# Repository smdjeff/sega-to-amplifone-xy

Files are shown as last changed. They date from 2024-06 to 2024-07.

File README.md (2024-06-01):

# sega-to-amplifone-vector
Sega G80 vector to Atari Amplifone adapter

* Converts Sega's vector outputs to Atari Amplifone levels and provides buffering.
* Input supply is +5V.
* The board makes +/-12v +/-9v and +0.5v on board.
* High quality TLE2082CP can be used to double bandwidth and slew vs older TL082 op-amps.
* Doubles voltage for X & Y to reduce stress on Sega XY game board amplifiers 
* Corrects black level and scale for RGB color signals
* Simulated Sega G08 vector impedance for Sega XY board

| | Sega  | Atari |
| --- | ----- | ----- |
| X | +/-4v | +/-8v |
| Y | +/-3v | +/-6v |
| R | 0-4v  | 1.0-3.5v |
| G | 0-4v  | 1.0-3.5v |
| B | 0-4v  | 1.0-3.5v |

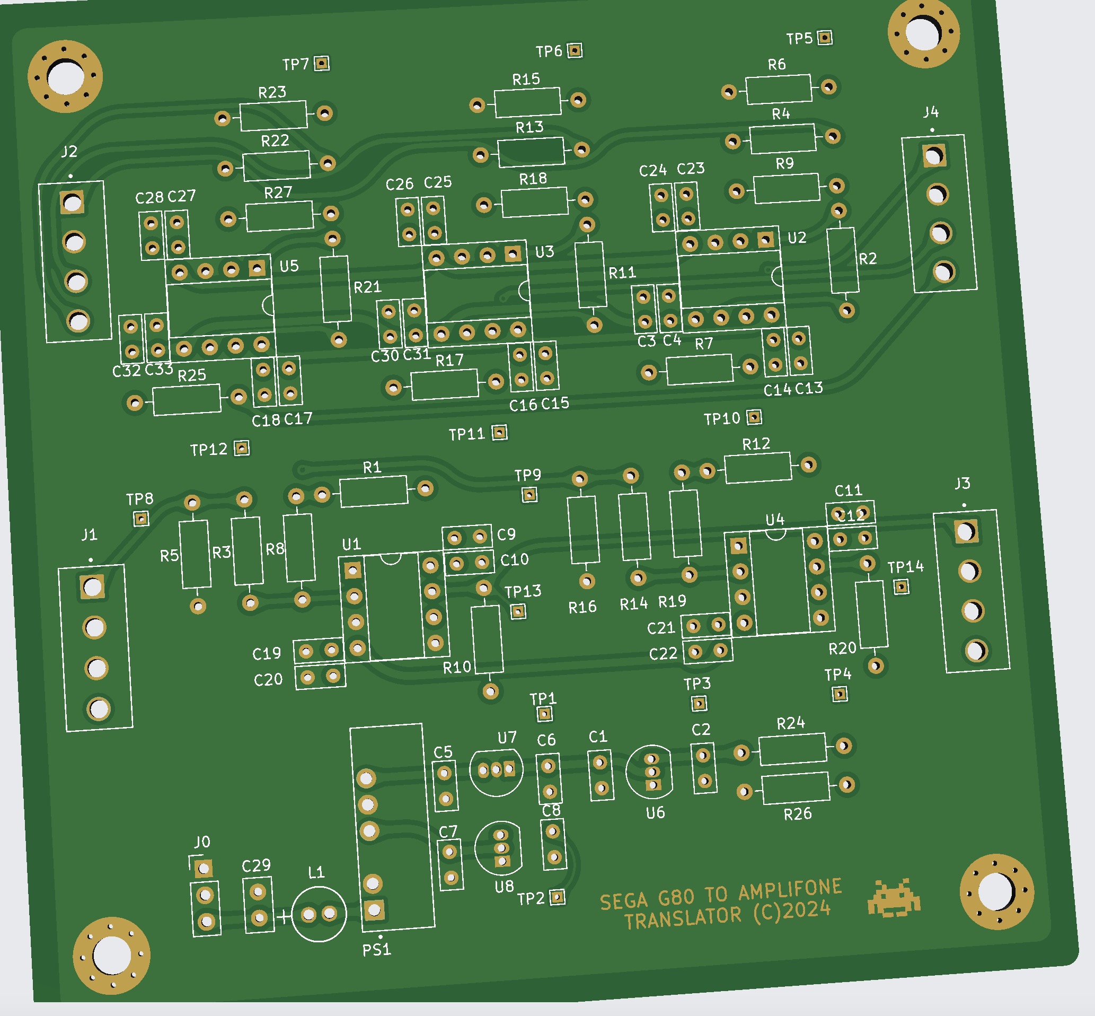
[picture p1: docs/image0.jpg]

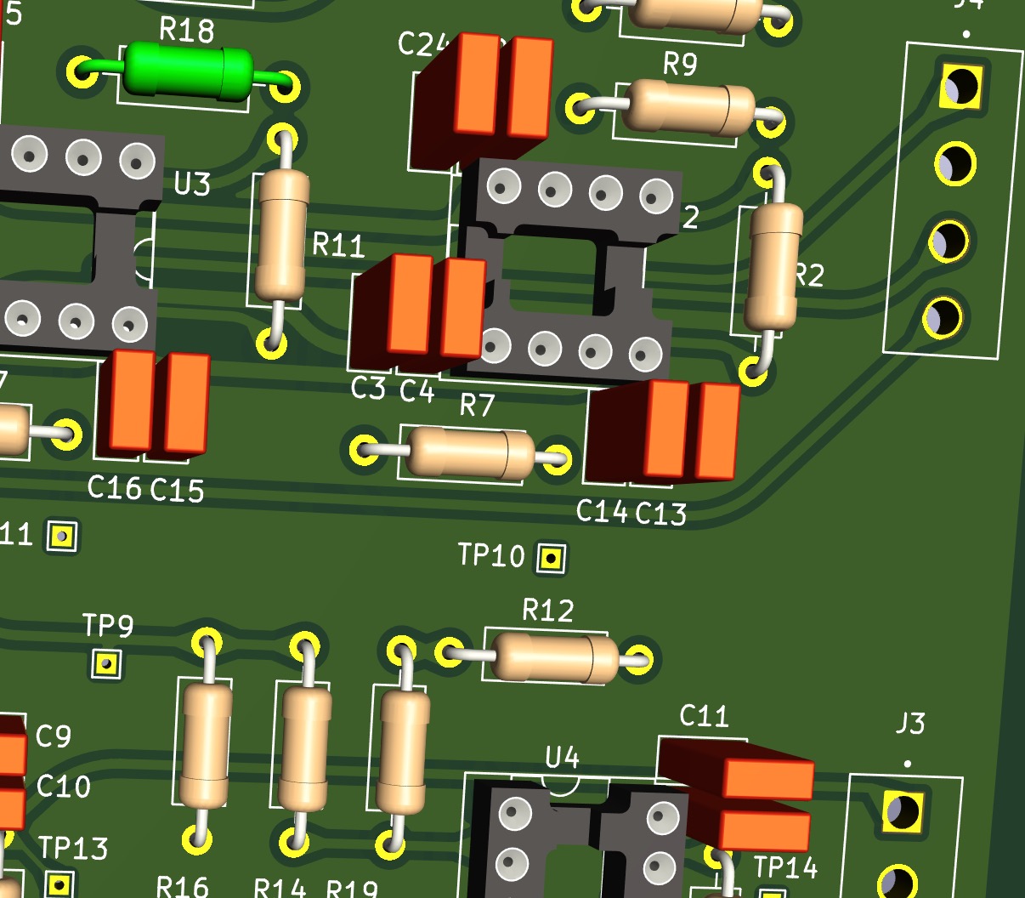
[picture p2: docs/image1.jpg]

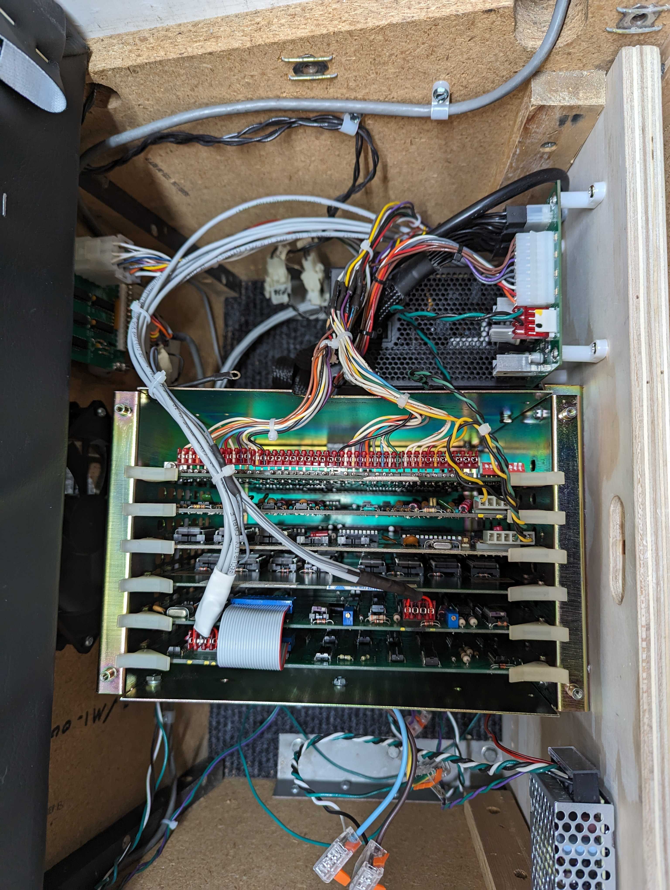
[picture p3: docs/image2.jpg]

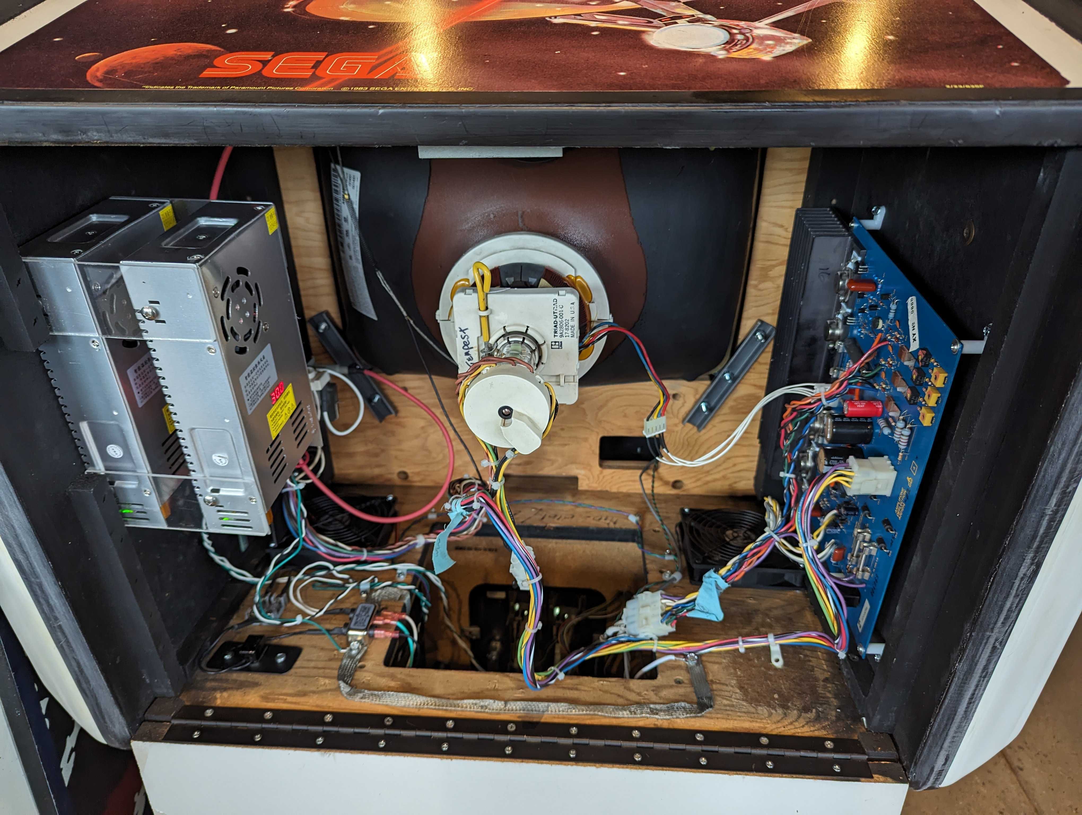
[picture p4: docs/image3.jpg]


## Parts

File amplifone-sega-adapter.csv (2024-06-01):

Id | Designator | Footprint | Quantity | Designation | Supplier and ref
1 | C33,C31,C9,C4,C15,C6,C19,C21,C17,C13,C23,C25,C8,C11,C27 | C_Rect_L4.6mm_W2.0mm_P2.50mm_MKS02_FKP02 | 15 | .1uF
2 | C32,C30,C24,C16,C12,C10,C26,C18,C28,C20,C14,C22,C3 | C_Rect_L4.6mm_W2.0mm_P2.50mm_MKS02_FKP02 | 13 | .01uF
3 | R3,R21,R7,R22,R2,R25,R11,R17,R13,R4,R12,R14,R1 | R_Axial_DIN0207_L6.3mm_D2.5mm_P10.16mm_Horizontal | 13 | 10k
4 | J4,J3,J1,J2 | TE_640385-4 | 4 | 640385-4
5 | R9,R18,R27 | R_Axial_DIN0207_L6.3mm_D2.5mm_P10.16mm_Horizontal | 3 | 6.3k
6 | TP12,TP6,TP9,TP2,TP1,TP7,TP10,TP13,TP8,TP3,TP4,TP11,TP14,TP5 | TestPoint_THTPad_1.0x1.0mm_Drill0.5mm | 14 | TestPoint
7 | R8,R19 | R_Axial_DIN0207_L6.3mm_D2.5mm_P10.16mm_Horizontal | 2 | 10K
8 | U5,U4,U2,U1,U3 | DIP-8_W7.62mm_Socket | 5 | TL082
9 | R5,R16 | R_Axial_DIN0207_L6.3mm_D2.5mm_P10.16mm_Horizontal | 2 | 14k
10 | PS1 | CONV_RD-0512D | 1 | RD-0512D
11 | U8 | TO-92_Inline | 1 | DI79L09ZAB
12 | R6,R23,R15 | R_Axial_DIN0207_L6.3mm_D2.5mm_P10.16mm_Horizontal | 3 | 2.7k
13 | C5,C7 | C_Rect_L4.6mm_W2.0mm_P2.50mm_MKS02_FKP02 | 2 | .33uF
14 | C29 | C_Disc_D5.0mm_W2.5mm_P2.50mm | 1 | 10uF CER
15 | C1,C2 | C_Rect_L4.6mm_W2.0mm_P2.50mm_MKS02_FKP02 | 2 | 1uF
16 | R10,R20 | R_Axial_DIN0207_L6.3mm_D2.5mm_P10.16mm_Horizontal | 2 | 20K
17 | U6 | TO-92_Inline | 1 | MCP1702-1502E/TO
18 | R26 | R_Axial_DIN0207_L6.3mm_D2.5mm_P10.16mm_Horizontal | 1 | 50k
19 | U7 | TO-92_Inline | 1 | DI78L09ZAB
20 | J0 | PinHeader_1x03_P2.54mm_Vertical | 1 | Conn_01x03_Male
21 | L1 | 1100R_MUR | 1 | 22uH
22 | R24 | R_Axial_DIN0207_L6.3mm_D2.5mm_P10.16mm_Horizontal | 1 | 100k

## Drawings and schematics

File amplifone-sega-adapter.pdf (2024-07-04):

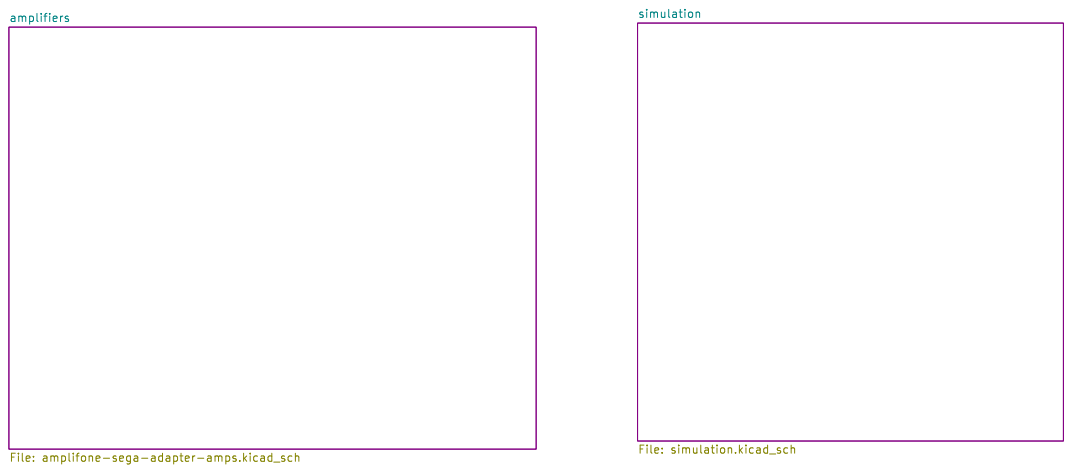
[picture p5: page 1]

amplifiers File: amplifone-sega-adapter-amps.kicad_sch

Id: 1/3 Title: File: amplifone-sega-adapter.kicad_sch Sheet: /

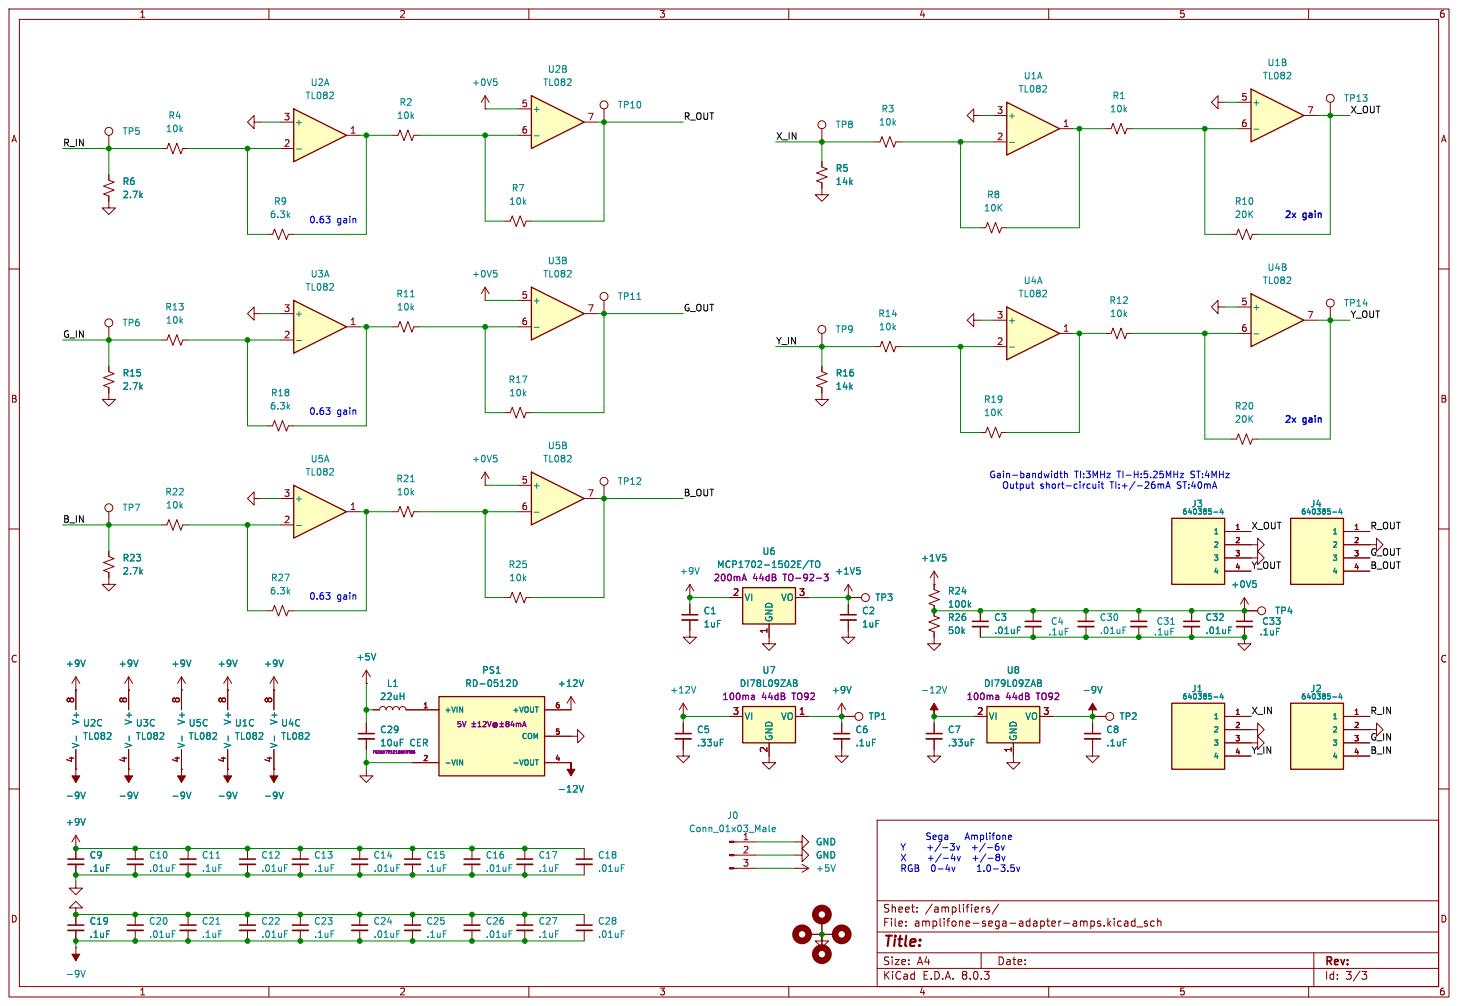
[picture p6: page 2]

Id: 3/3 Title: File: amplifone-sega-adapter-amps.kicad_sch Sheet: /amplifiers/

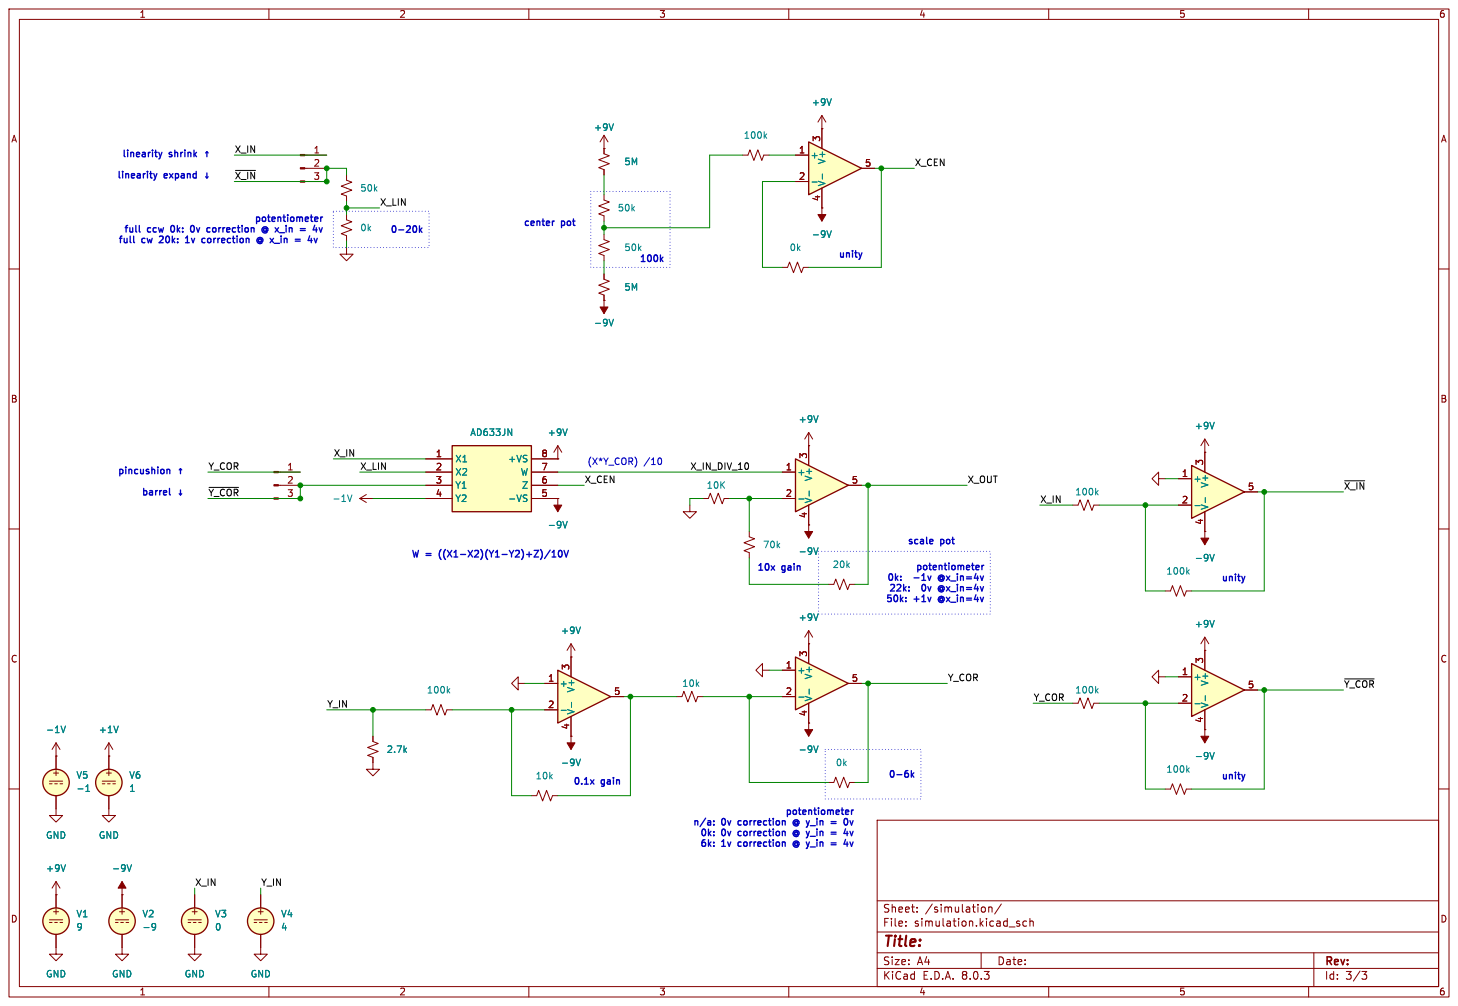
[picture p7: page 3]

(X*Y_COR) /10 pincushion þÿ!‘ barrel þÿ!“

Id: 3/3 Title: File: simulation.kicad_sch Sheet: /simulation/ GND

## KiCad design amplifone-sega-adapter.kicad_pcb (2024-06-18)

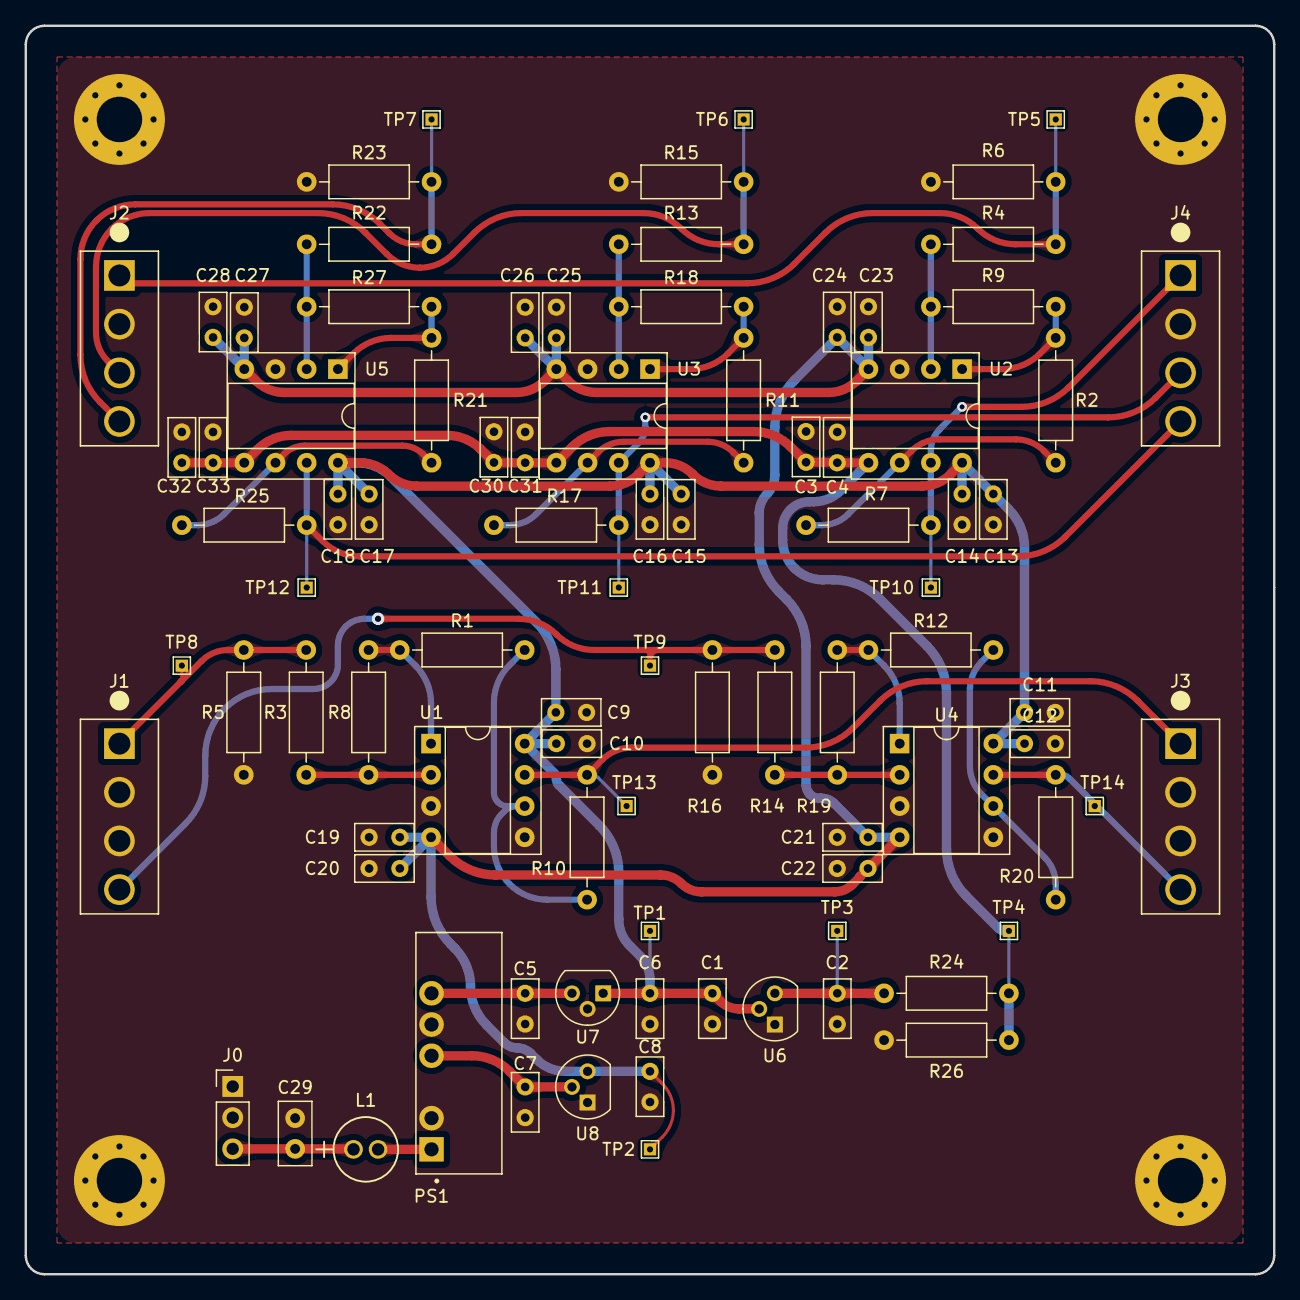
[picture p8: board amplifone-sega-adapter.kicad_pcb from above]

Board: 2 copper layers, 101.6 x 101.6 mm, 93 parts (0 on the bottom side), 34 nets.

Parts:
C1, C2: 1uF; C_Rect_L4.6mm_W2.0mm_P2.50mm_MKS02_FKP02
C3, C10, C12, C14, C16, C18, C20, C22, C24, C26, C28, C30, C32: .01uF; C_Rect_L4.6mm_W2.0mm_P2.50mm_MKS02_FKP02
C4, C6, C8, C9, C11, C13, C15, C17, C19, C21, C23, C25, C27, C31, C33: .1uF; C_Rect_L4.6mm_W2.0mm_P2.50mm_MKS02_FKP02
C5, C7: .33uF; C_Rect_L4.6mm_W2.0mm_P2.50mm_MKS02_FKP02
C29: 10uF CER; C_Disc_D5.0mm_W2.5mm_P2.50mm
H1, H2, H3, H4: MountingHole_Pad; MountingHole_3.7mm_Pad_Via
J0: Conn_01x03_Male; PinHeader_1x03_P2.54mm_Vertical
J1, J2, J3, J4: 640385-4; TE_640385-4
L1: 22uH; 1100R_MUR
PS1: RD-0512D; CONV_RD-0512D
R1, R2, R3, R4, R7, R11, R12, R13, R14, R17, R21, R22, R25: 10k; R_Axial_DIN0207_L6.3mm_D2.5mm_P10.16mm_Horizontal
R5, R16: 14k; R_Axial_DIN0207_L6.3mm_D2.5mm_P10.16mm_Horizontal
R6, R15, R23: 2.7k; R_Axial_DIN0207_L6.3mm_D2.5mm_P10.16mm_Horizontal
R8, R19: 10K; R_Axial_DIN0207_L6.3mm_D2.5mm_P10.16mm_Horizontal
R9, R18, R27: 6.3k; R_Axial_DIN0207_L6.3mm_D2.5mm_P10.16mm_Horizontal
R10, R20: 20K; R_Axial_DIN0207_L6.3mm_D2.5mm_P10.16mm_Horizontal
R24: 100k; R_Axial_DIN0207_L6.3mm_D2.5mm_P10.16mm_Horizontal
R26: 50k; R_Axial_DIN0207_L6.3mm_D2.5mm_P10.16mm_Horizontal
TP1, TP2, TP3, TP4, TP5, TP6, TP7, TP8, TP9, TP10, TP11, TP12, TP13, TP14: TestPoint; TestPoint_THTPad_1.0x1.0mm_Drill0.5mm
U1, U2, U3, U4, U5: TL082; DIP-8_W7.62mm_Socket
U6: MCP1702-1502E/TO; TO-92
U7: DI78L09ZAB; TO-92
U8: DI79L09ZAB; TO-92

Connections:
+0V5: C3.1, C4.1, C30.1, C31.1, C32.1, C33.1, R24.1, R26.2, TP4.1, U2.5 (+), U3.5 (+), U5.5 (+)
+1V5: C2.1, R24.2, TP3.1, U6.3 (VO)
+5V: C29.1, J0.3, L1.1
+9V: C1.1, C6.1, C9.1, C10.1, C11.1, C12.1, C13.1, C14.1, C15.1, C16.1, C17.1, C18.1, TP1.1, U1.8 (V+), U2.8 (V+), U3.8 (V+), U4.8 (V+), U5.8 (V+), U6.2 (VI), U7.1 (VO)
+12V: C5.1, PS1.6 (+VOUT), U7.3 (VI)
-9V: C8.1, C19.2, C20.2, C21.2, C22.2, C23.2, C24.2, C25.2, C26.2, C27.2, C28.2, TP2.1, U1.4 (V-), U2.4 (V-), U3.4 (V-), U4.4 (V-), U5.4 (V-), U8.3 (VO)
-12V: C7.1, PS1.4 (-VOUT), U8.2 (VI)
/amplifiers/B_IN: J2.4, R22.1, R23.2, TP7.1
/amplifiers/B_OUT: J4.4, R25.2, TP12.1, U5.7
/amplifiers/G_IN: J2.3, R13.1, R15.2, TP6.1
/amplifiers/G_OUT: J4.3, R17.2, TP11.1, U3.7
/amplifiers/R_IN: J2.1, R4.1, R6.2, TP5.1
/amplifiers/R_OUT: J4.1, R7.2, TP10.1, U2.7
/amplifiers/X_IN: J1.1, R3.1, R5.1, TP8.1
/amplifiers/X_OUT: J3.1, R10.2, TP13.1, U1.7
/amplifiers/Y_IN: J1.4, R14.1, R16.1, TP9.1
/amplifiers/Y_OUT: J3.4, R20.2, TP14.1, U4.7
GND: C1.2, C2.2, C3.2, C4.2, C5.2, C6.2, C7.2, C8.2, C9.2, C10.2, C11.2, C12.2, C13.2, C14.2, C15.2, C16.2, C17.2, C18.2, C19.1, C20.1, C21.1, C22.1, C23.1, C24.1, C25.1, C26.1, C27.1, C28.1, C29.2, C30.2, C31.2, C32.2, C33.2, H1.1, H2.1, H3.1, H4.1, J0.1, J0.2, J1.2, J1.3, J2.2, J3.2, J3.3, J4.2, PS1.2 (-VIN), PS1.5 (COM), R5.2, R6.1, R15.1, R16.2, R23.1, R26.1, U1.3 (+), U1.5 (+), U2.3 (+), U3.3 (+), U4.3 (+), U4.5 (+), U5.3 (+), U6.1 (GND), U7.2 (GND), U8.1 (GND)
unnamed: L1.2, PS1.1 (+VIN)
unnamed: R1.1, R8.2, U1.1
unnamed: R2.1, R9.2, U2.1
unnamed: R11.1, R18.2, U3.1
unnamed: R12.1, R19.2, U4.1
unnamed: R21.1, R27.2, U5.1
unnamed: R3.2, R8.1, U1.2 (-)
unnamed: R1.2, R10.1, U1.6 (-)
unnamed: R4.2, R9.1, U2.2 (-)
unnamed: R2.2, R7.1, U2.6 (-)
unnamed: R13.2, R18.1, U3.2 (-)
unnamed: R11.2, R17.1, U3.6 (-)
unnamed: R14.2, R19.1, U4.2 (-)
unnamed: R12.2, R20.1, U4.6 (-)
unnamed: R22.2, R27.1, U5.2 (-)
unnamed: R21.2, R25.1, U5.6 (-)

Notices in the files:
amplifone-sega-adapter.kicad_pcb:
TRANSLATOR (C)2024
